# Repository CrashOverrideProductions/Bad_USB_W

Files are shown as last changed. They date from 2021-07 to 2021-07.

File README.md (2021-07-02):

# BadUSB-W 

### Project: Arduino and ESP32 Based WiFi Capable Malicious USB 

<!-- Repo Cover Image -->
<p style="background-color:rgba(22,22,22,1.00)" align="center">
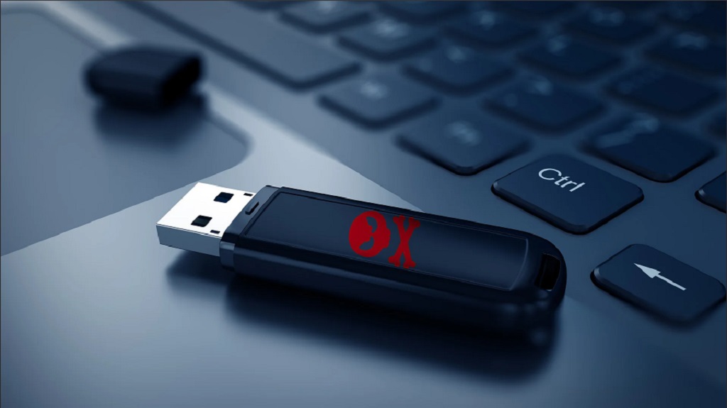
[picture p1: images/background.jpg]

</p>

<!-- Repo Stats -->
   

## Details
The BadUSB is intended to be a budget alternative to the current offering of Keystroke Injection tools available on the market.

### What is a Keystroke Injection Attack?
A Keystroke Injection Attack Tool is a specially designed USB device, often disguised as a thumb drive, that automatically runs code on any host computer into which it is plugged. It does so by appearing to the computer as a USB HID ('Human Interface Device') keyboard and/or mouse, and then “typing” in keyboard shortcuts and commands.

This can be a vector for malicious code, and is potentially dangerous and destructive! This project aims to educate you and your “victim” on the dangers of these devices. Nothing is quite so memorable a lesson in security as plugging in an innocent looking device and being met with a flurry of terminal windows and text popping up, and receiving an automatically deployed desktop background that says “You just go PWND, be more careful next time!"

---
<!-- To Do List -->
## To Do List
- [X] Complete Readme.md
- [X] Build & Test Prototype
- [ ] Design Schematic
- [ ] Finalise Software
- [ ] Design Board
- [ ] Order Prototype PCBs
- [ ] Design 3D Print Shell
- [ ] Research Injection Moulded Shell

---
## Prototype Design

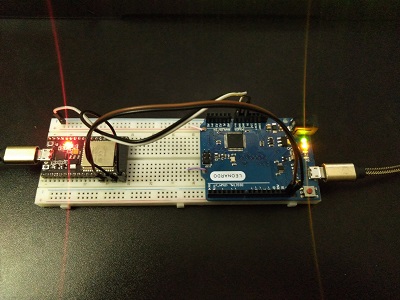
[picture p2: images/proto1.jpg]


### BOM
```
| COMPONENT         | QTY | AUD$   |
|===================|=====|========|
| ESP32 DEVKIT V1   |  1  | $39.95 |
| ARDUINO LEONARDO  |  1  | $29.95 |
```

### Software
The software for this project is a modified version of the WiFi Duck firmware developed by [SpaceHunn](https://github.com/SpacehuhnTech/WiFiDuck "SpaceHunn") released under the MIT Licence.

### Hardware Configuration
```
| LEONARDO          | ESP32 DEVKIT V1 | SIGNAL NAME |
|===================|=================|=============|
| SCL               | GPIO-22         | I2C SCL     |
| SDA               | GPIO-21         | I2C SDA     |
| GND               | GND             | GND         |
```

<!-- Licencing Always at the Bottom -->
------------
### Licencing 

**Creative Commons: Attribution - NonCommercial - ShareAlike 4.0 International (CC BY-NC-SA 4.0)**

**You are free to:**

**Share** — copy and redistribute the material in any medium or format

**Adapt** — remix, transform, and build upon the material

**Under the following terms:**

**Attribution** — You must give appropriate credit, provide a link to the license, and indicate if changes were made. You may do so in any reasonable manner, but not in any way that suggests the licensor endorses you or your use.

**NonCommercial** — You may not use the material for commercial purposes.

**ShareAlike** — If you remix, transform, or build upon the material, you must distribute your contributions under the same license as the original.

No additional restrictions — You may not apply legal terms or technological measures that legally restrict others from doing anything the license permits.

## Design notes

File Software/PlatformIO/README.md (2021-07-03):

# BadUSB-W Firmware 

### Project: PlatformIO Migration of BadUSB-W Firmware (WiFi Duck Modified) 



#### NOTE: THIS FIRMWARE IS CURRENTLY BEING MODIFIED FOR USE ON AN ESP32

#### ChangeLog
```c++
// PlatformIO Migration
22/05/2021  IMPORT SpacehuhnTech/WiFiDuck
22/05/2021  MIGRATE ESP_DUCK TO PLATFORMIO
22/05/2021  MIGRATE ATMEGA_DUCK TO PLATFORMIO

// ESP32 Migration
Date          File            Changes
==========    ============    ===================================================================
01/07/2021    cli.cpp         Comment out xtern "C" functions
01/07/2021    config.h        Enable Debugging
                              Enable I2C & Set Pin SDA-21/SCL-22
                              Change WiFi Settings (See WiFi Setting Below)
                              Change Sanity Check to from ESP8266 to ESP32
01/07/2021                    Manually Add Libraries "EEPROM" & "SPIFFS"
01/07/2021    eeprom.h        Change #include "<EEPROM.h>" to "#include "Libraries/EEPROM.h" "
01/07/2021    spiffs.cpp      Append "FILE_NAME" var with ".txt"
                              Change "size()" function to suit (See Addendum)
                              Change "usedBytes()" function to suit (See Addendum)
                              Change "freeBytes()" function to suit (See Addendum)
                              Change "size(String fileName)" function to suit (See Addendum)
                              Change "open(String fileName)" function to suit (See Addendum)
                              Change "create(String fileName)" function to suit (See Addendum)
                              Change "listDir(String dirName)" function to suit (See Addendum)
01/07/2021    spiffs.h        Add "#include "Libraries/SPIFFS.h"" 
                              Change "#include <FS.h>" to #include "Libraries/FS.h"
01/07/2021    webserver.cpp   Change "#include <ESP8266WiFi.h>" to "#include <WiFi.h>"
                              Change "#include <ESP8266mDNS.h>" to "#include <ESPmDNS.h>"
                              Change "#include <ESPAsyncTCP.h>" to "#include <AsyncTCP.h>"
                              omment out "Update.runAsync(true);"
```

ChangeLog Addendum
``` C++
spiffs.cpp
=============================================================================================
Change "size()" function to suit
    -------------------------------------------------------------------------
      // OLD FUNCTION
          size_t size() {
              FSInfo fs_info;

              SPIFFS.info(fs_info);
              return fs_info.totalBytes;
          }

      // NEW FUNCTION
          size_t size() {
              unsigned int totalBytes = SPIFFS.totalBytes();
              return totalBytes;
          }
    -------------------------------------------------------------------------

Change "usedBytes()" function to suit
    -------------------------------------------------------------------------
      // OLD FUNCTION
          size_t usedBytes() {
              FSInfo fs_info;

              SPIFFS.info(fs_info);
              return fs_info.usedBytes;
          }

      // NEW FUNCTION
          size_t usedBytes() {
            unsigned int usedBytes = SPIFFS.usedBytes();
            return usedBytes;
          }
    -------------------------------------------------------------------------

Change "freeBytes()" function to suit (See Addendum)
    -------------------------------------------------------------------------
      // OLD FUNCTION
          size_t freeBytes() {
                  FSInfo fs_info;

                  SPIFFS.info(fs_info);
                  return fs_info.totalBytes - fs_info.usedBytes;
              }

      // NEW FUNCTION
          size_t freeBytes() {
                  unsigned int totalBytes = SPIFFS.totalBytes();
                  unsigned int usedBytes = SPIFFS.usedBytes();

                  return (totalBytes - usedBytes);
              }
    -------------------------------------------------------------------------

Change "size(String fileName)" function to suit (See Addendum)
    -------------------------------------------------------------------------
      // OLD FUNCTION
            size_t size(String fileName) {
                fixPath(fileName);

                File f = SPIFFS.open(fileName, "r");

                return f.size();
            }

      // NEW FUNCTION
            size_t size(String fileName) {
                fixPath(fileName);

                File f = SPIFFS.open(fileName, FILE_READ);

                return f.size();
            }
    -------------------------------------------------------------------------

Change "open(String fileName)" function to suit (See Addendum)
    -------------------------------------------------------------------------
      // OLD FUNCTION
            File open(String fileName) {
                    fixPath(fileName);

                    return SPIFFS.open(fileName, "a+");
                }

      // NEW FUNCTION
            File open(String fileName) {
                fixPath(fileName);

                File file = SPIFFS.open(fileName, "r+");

                return file;
            }
    -------------------------------------------------------------------------

Change "create(String fileName)" function to suit (See Addendum)
    -------------------------------------------------------------------------
      // OLD FUNCTION
            void create(String fileName) {
              fixPath(fileName);

              File f = SPIFFS.open(fileName, "a+");

              f.close();
            }

      // NEW FUNCTION
            void create(String fileName) {
                    fixPath(fileName);

                    File f = SPIFFS.open(fileName, FILE_APPEND);

                    f.close();
            }
    -------------------------------------------------------------------------

Change "listDir(String dirName)" function to suit (See Addendum)
    -------------------------------------------------------------------------
      // OLD FUNCTION
            String listDir(String dirName) {
              String res;

              fixPath(dirName);

              Dir dir = SPIFFS.openDir(dirName);

              while (dir.next()) {
                  res += dir.fileName();
                  res += ' ';
                  res += size(dir.fileName());
                  res += '\n';
              }

              if (res.length() == 0) {
                  res += "\n";
              }

              return res;
            }
      // NEW FUNCTION
            String listDir(String dirName) {
                String res;

                fixPath(dirName);

                File root = SPIFFS.open(dirName);
              
                if(!root)
                {
                  debugln("failed to open directory");
                  return("Error!");
              }

                File file = root.openNextFile();
                while(file)
                {
                    //debugln(file.name());
                    res += file.name();
                    res += ' ';
                    res += size(file.name());
                    res += '\n';
                          
                    file = root.openNextFile();
                }

                if (res.length() == 0) 
                {
                    res += "\n";
                }
                    return res;
            }
    -------------------------------------------------------------------------

```

#### WiFi Settings
```python
WIFI_SSID       "BadUSBw"
WIFI_PASSWORD   "BadUSBW"
WIFI_CHANNEL    "1"
HOSTNAME        "badusb"
URL             "bad.usb"
```

#### Platform IO Build Status
##### ATMEGA_DUCK
```c++
Processing leonardo (platform: atmelavr; board: leonardo; framework: arduino)
------------------------------------------------------------------------------------------
Verbose mode can be enabled via `-v, --verbose` option
CONFIGURATION: https://docs.platformio.org/page/boards/atmelavr/leonardo.html
PLATFORM: Atmel AVR (3.3.0) > Arduino Leonardo    
HARDWARE: ATMEGA32U4 16MHz, 2.50KB RAM, 28KB Flash
DEBUG: Current (simavr) On-board (simavr)
PACKAGES:
 - framework-arduino-avr 5.1.0
 - toolchain-atmelavr 1.70300.191015 (7.3.0)      
LDF: Library Dependency Finder -> http://bit.ly/configure-pio-ldf
LDF Modes: Finder ~ chain, Compatibility ~ soft
Found 5 compatible libraries
Scanning dependencies...
Dependency Graph
|-- <SPI> 1.0 
|-- <Wire> 1.0
|-- <HID> 1.0 
Building in release mode
Compiling .pio\build\leonardo\src\Adafruit_DotStar.cpp.o
Compiling .pio\build\leonardo\src\NeoPixel.cpp.o
Compiling .pio\build\leonardo\src\atmega_duck.cpp.o
Compiling .pio\build\leonardo\src\com.cpp.o
Compiling .pio\build\leonardo\src\duckparser.cpp.o
Compiling .pio\build\leonardo\src\keyboard.cpp.o
Compiling .pio\build\leonardo\src\led.cpp.o
Compiling .pio\build\leonardo\src\parser.c.o
Compiling .pio\build\leonardo\FrameworkArduino\HardwareSerial.cpp.o
Compiling .pio\build\leonardo\FrameworkArduino\HardwareSerial0.cpp.o
Compiling .pio\build\leonardo\FrameworkArduino\HardwareSerial1.cpp.o
Archiving .pio\build\leonardo\lib675\libSPI.a
Compiling .pio\build\leonardo\FrameworkArduino\HardwareSerial2.cpp.o
Archiving .pio\build\leonardo\libdea\libWire.a
Archiving .pio\build\leonardo\lib370\libHID.a
Compiling .pio\build\leonardo\FrameworkArduino\HardwareSerial3.cpp.o
Compiling .pio\build\leonardo\FrameworkArduino\IPAddress.cpp.o
Compiling .pio\build\leonardo\FrameworkArduino\PluggableUSB.cpp.o
Compiling .pio\build\leonardo\FrameworkArduino\Print.cpp.o
Compiling .pio\build\leonardo\FrameworkArduino\Stream.cpp.o
Compiling .pio\build\leonardo\FrameworkArduino\Tone.cpp.o
Compiling .pio\build\leonardo\FrameworkArduino\USBCore.cpp.o
Compiling .pio\build\leonardo\FrameworkArduino\WInterrupts.c.o
Compiling .pio\build\leonardo\FrameworkArduino\WMath.cpp.o
Compiling .pio\build\leonardo\FrameworkArduino\WString.cpp.o
Compiling .pio\build\leonardo\FrameworkArduino\abi.cpp.o
Compiling .pio\build\leonardo\FrameworkArduino\hooks.c.o
Compiling .pio\build\leonardo\FrameworkArduino\main.cpp.o
Compiling .pio\build\leonardo\FrameworkArduino\new.cpp.o
Compiling .pio\build\leonardo\FrameworkArduino\wiring.c.o
Compiling .pio\build\leonardo\FrameworkArduino\wiring_analog.c.o
Compiling .pio\build\leonardo\FrameworkArduino\wiring_digital.c.o
Compiling .pio\build\leonardo\FrameworkArduino\wiring_pulse.S.o
Compiling .pio\build\leonardo\FrameworkArduino\wiring_pulse.c.o
Compiling .pio\build\leonardo\FrameworkArduino\wiring_shift.c.o
Archiving .pio\build\leonardo\libFrameworkArduino.a
Linking .pio\build\leonardo\firmware.elf
Checking size .pio\build\leonardo\firmware.elf
Advanced Memory Usage is available via "PlatformIO Home > Project Inspect"
RAM:   [======    ]  63.7% (used 1630 bytes from 2560 bytes)
Flash: [=====     ]  50.6% (used 14500 bytes from 28672 bytes)
Building .pio\build\leonardo\firmware.hex
=========================== [SUCCESS] Took 7.83 seconds ==================================
```

##### ESP_DUCK
```c++

Processing esp32doit-devkit-v1 (platform: espressif32; board: esp32doit-devkit-v1; framework: arduino)
------------------------------------------------------------------------------------------------------
Verbose mode can be enabled via `-v, --verbose` option
CONFIGURATION: https://docs.platformio.org/page/boards/espressif32/esp32doit-devkit-v1.html
PLATFORM: Espressif 32 (3.2.1) > DOIT ESP32 DEVKIT V1
HARDWARE: ESP32 240MHz, 320KB RAM, 4MB Flash
DEBUG: Current (esp-prog) External (esp-prog, iot-bus-jtag, jlink, minimodule, olimex-arm-usb-ocd,
 olimex-arm-usb-ocd-h, olimex-arm-usb-tiny-h, olimex-jtag-tiny, tumpa)
PACKAGES:
 - framework-arduinoespressif32 3.10006.210326 (1.0.6)
 - tool-esptoolpy 1.30000.201119 (3.0.0)
 - toolchain-xtensa32 2.50200.97 (5.2.0)
LDF: Library Dependency Finder -> http://bit.ly/configure-pio-ldf
LDF Modes: Finder ~ chain, Compatibility ~ soft
Found 31 compatible libraries
Scanning dependencies...
Dependency Graph
|-- <SimpleCLI> 1.1.1
|-- <ESP Async WebServer> 1.2.3
|   |-- <AsyncTCP> 1.1.1       
|   |-- <FS> 1.0
|   |-- <WiFi> 1.0
|-- <Wire> 1.0.1
|-- <ArduinoOTA> 1.0
|   |-- <Update> 1.0
|   |-- <WiFi> 1.0
|   |-- <ESPmDNS> 1.0
|   |   |-- <WiFi> 1.0
|-- <AsyncTCP> 1.1.1
|-- <DNSServer> 1.1.0
|   |-- <WiFi> 1.0
|-- <ESPmDNS> 1.0
|   |-- <WiFi> 1.0
|-- <WiFi> 1.0
Building in release mode
Compiling .pio\build\esp32doit-devkit-v1\src\Libraries\EEPROM.cpp.o
Compiling .pio\build\esp32doit-devkit-v1\src\Libraries\FS.cpp.o
Compiling .pio\build\esp32doit-devkit-v1\src\Libraries\SPIFFS.cpp.o
Compiling .pio\build\esp32doit-devkit-v1\src\Libraries\vfs_api.cpp.o
Compiling .pio\build\esp32doit-devkit-v1\src\cli.cpp.o
Compiling .pio\build\esp32doit-devkit-v1\src\com.cpp.o
Compiling .pio\build\esp32doit-devkit-v1\src\duckscript.cpp.o
Compiling .pio\build\esp32doit-devkit-v1\src\eeprom.cpp.o
Compiling .pio\build\esp32doit-devkit-v1\src\esp_duck.cpp.o
Compiling .pio\build\esp32doit-devkit-v1\src\settings.cpp.o
Compiling .pio\build\esp32doit-devkit-v1\src\spiffs.cpp.o
Compiling .pio\build\esp32doit-devkit-v1\src\webserver.cpp.o
Generating partitions .pio\build\esp32doit-devkit-v1\partitions.bin
Compiling .pio\build\esp32doit-devkit-v1\lib176\SimpleCLI\Argument.cpp.o
Compiling .pio\build\esp32doit-devkit-v1\lib176\SimpleCLI\Command.cpp.o
Compiling .pio\build\esp32doit-devkit-v1\lib176\SimpleCLI\CommandError.cpp.o
Compiling .pio\build\esp32doit-devkit-v1\lib176\SimpleCLI\SimpleCLI.cpp.o
Compiling .pio\build\esp32doit-devkit-v1\lib176\SimpleCLI\c\arg.c.o
Compiling .pio\build\esp32doit-devkit-v1\lib176\SimpleCLI\c\cmd.c.o
Compiling .pio\build\esp32doit-devkit-v1\lib176\SimpleCLI\c\cmd_error.c.o
Compiling .pio\build\esp32doit-devkit-v1\lib176\SimpleCLI\c\comparator.c.o
Compiling .pio\build\esp32doit-devkit-v1\lib176\SimpleCLI\c\parser.c.o
Compiling .pio\build\esp32doit-devkit-v1\libb5f\AsyncTCP\AsyncTCP.cpp.o
Compiling .pio\build\esp32doit-devkit-v1\libb9a\FS\FS.cpp.o
Compiling .pio\build\esp32doit-devkit-v1\libb9a\FS\vfs_api.cpp.o
Compiling .pio\build\esp32doit-devkit-v1\libb1c\WiFi\ETH.cpp.o
Compiling .pio\build\esp32doit-devkit-v1\libb1c\WiFi\WiFi.cpp.o
Compiling .pio\build\esp32doit-devkit-v1\libb1c\WiFi\WiFiAP.cpp.o
Archiving .pio\build\esp32doit-devkit-v1\lib176\libSimpleCLI.a
Compiling .pio\build\esp32doit-devkit-v1\libb1c\WiFi\WiFiClient.cpp.o
Compiling .pio\build\esp32doit-devkit-v1\libb1c\WiFi\WiFiGeneric.cpp.o
Compiling .pio\build\esp32doit-devkit-v1\libb1c\WiFi\WiFiMulti.cpp.o
Archiving .pio\build\esp32doit-devkit-v1\libb9a\libFS.a
Compiling .pio\build\esp32doit-devkit-v1\libb1c\WiFi\WiFiSTA.cpp.o
Compiling .pio\build\esp32doit-devkit-v1\libb1c\WiFi\WiFiScan.cpp.o
Archiving .pio\build\esp32doit-devkit-v1\libb5f\libAsyncTCP.a
Compiling .pio\build\esp32doit-devkit-v1\libb1c\WiFi\WiFiServer.cpp.o
Compiling .pio\build\esp32doit-devkit-v1\libb1c\WiFi\WiFiUdp.cpp.o
Compiling .pio\build\esp32doit-devkit-v1\lib632\ESP Async WebServer\AsyncEventSource.cpp.o
Compiling .pio\build\esp32doit-devkit-v1\lib632\ESP Async WebServer\AsyncWebSocket.cpp.o
Compiling .pio\build\esp32doit-devkit-v1\lib632\ESP Async WebServer\SPIFFSEditor.cpp.o
Compiling .pio\build\esp32doit-devkit-v1\lib632\ESP Async WebServer\WebAuthentication.cpp.o
Compiling .pio\build\esp32doit-devkit-v1\lib632\ESP Async WebServer\WebHandlers.cpp.o
Compiling .pio\build\esp32doit-devkit-v1\lib632\ESP Async WebServer\WebRequest.cpp.o
Compiling .pio\build\esp32doit-devkit-v1\lib632\ESP Async WebServer\WebResponses.cpp.o
Archiving .pio\build\esp32doit-devkit-v1\libb1c\libWiFi.a
Compiling .pio\build\esp32doit-devkit-v1\lib632\ESP Async WebServer\WebServer.cpp.o
Compiling .pio\build\esp32doit-devkit-v1\lib068\Wire\Wire.cpp.o
Compiling .pio\build\esp32doit-devkit-v1\lib178\Update\HttpsOTAUpdate.cpp.o
Compiling .pio\build\esp32doit-devkit-v1\lib178\Update\Updater.cpp.o
Compiling .pio\build\esp32doit-devkit-v1\libcf5\ESPmDNS\ESPmDNS.cpp.o
Compiling .pio\build\esp32doit-devkit-v1\liba79\ArduinoOTA\ArduinoOTA.cpp.o
Compiling .pio\build\esp32doit-devkit-v1\libd96\DNSServer\DNSServer.cpp.o
Archiving .pio\build\esp32doit-devkit-v1\libFrameworkArduinoVariant.a
Compiling .pio\build\esp32doit-devkit-v1\FrameworkArduino\Esp.cpp.o
Archiving .pio\build\esp32doit-devkit-v1\lib068\libWire.a
Compiling .pio\build\esp32doit-devkit-v1\FrameworkArduino\FunctionalInterrupt.cpp.o
Compiling .pio\build\esp32doit-devkit-v1\FrameworkArduino\HardwareSerial.cpp.o
Archiving .pio\build\esp32doit-devkit-v1\lib178\libUpdate.a
Compiling .pio\build\esp32doit-devkit-v1\FrameworkArduino\IPAddress.cpp.o
Compiling .pio\build\esp32doit-devkit-v1\FrameworkArduino\IPv6Address.cpp.o
Archiving .pio\build\esp32doit-devkit-v1\libcf5\libESPmDNS.a
Compiling .pio\build\esp32doit-devkit-v1\FrameworkArduino\MD5Builder.cpp.o
Archiving .pio\build\esp32doit-devkit-v1\liba79\libArduinoOTA.a
Archiving .pio\build\esp32doit-devkit-v1\libd96\libDNSServer.a
Compiling .pio\build\esp32doit-devkit-v1\FrameworkArduino\Print.cpp.o
Compiling .pio\build\esp32doit-devkit-v1\FrameworkArduino\Stream.cpp.o
Compiling .pio\build\esp32doit-devkit-v1\FrameworkArduino\StreamString.cpp.o
Compiling .pio\build\esp32doit-devkit-v1\FrameworkArduino\WMath.cpp.o
Archiving .pio\build\esp32doit-devkit-v1\lib632\libESP Async WebServer.a
Compiling .pio\build\esp32doit-devkit-v1\FrameworkArduino\WString.cpp.o
Compiling .pio\build\esp32doit-devkit-v1\FrameworkArduino\base64.cpp.o
Compiling .pio\build\esp32doit-devkit-v1\FrameworkArduino\cbuf.cpp.o
Compiling .pio\build\esp32doit-devkit-v1\FrameworkArduino\esp32-hal-adc.c.o
Compiling .pio\build\esp32doit-devkit-v1\FrameworkArduino\esp32-hal-bt.c.o
Compiling .pio\build\esp32doit-devkit-v1\FrameworkArduino\esp32-hal-cpu.c.o
Compiling .pio\build\esp32doit-devkit-v1\FrameworkArduino\esp32-hal-dac.c.o
Compiling .pio\build\esp32doit-devkit-v1\FrameworkArduino\esp32-hal-gpio.c.o
Compiling .pio\build\esp32doit-devkit-v1\FrameworkArduino\esp32-hal-i2c.c.o
Compiling .pio\build\esp32doit-devkit-v1\FrameworkArduino\esp32-hal-ledc.c.o
Compiling .pio\build\esp32doit-devkit-v1\FrameworkArduino\esp32-hal-log.c.o
Compiling .pio\build\esp32doit-devkit-v1\FrameworkArduino\esp32-hal-matrix.c.o
Compiling .pio\build\esp32doit-devkit-v1\FrameworkArduino\esp32-hal-misc.c.o
Compiling .pio\build\esp32doit-devkit-v1\FrameworkArduino\esp32-hal-psram.c.o
Compiling .pio\build\esp32doit-devkit-v1\FrameworkArduino\esp32-hal-rmt.c.o
Compiling .pio\build\esp32doit-devkit-v1\FrameworkArduino\esp32-hal-sigmadelta.c.o
Compiling .pio\build\esp32doit-devkit-v1\FrameworkArduino\esp32-hal-spi.c.o
Compiling .pio\build\esp32doit-devkit-v1\FrameworkArduino\esp32-hal-time.c.o
Compiling .pio\build\esp32doit-devkit-v1\FrameworkArduino\esp32-hal-timer.c.o
Compiling .pio\build\esp32doit-devkit-v1\FrameworkArduino\esp32-hal-touch.c.o
Compiling .pio\build\esp32doit-devkit-v1\FrameworkArduino\esp32-hal-uart.c.o
Compiling .pio\build\esp32doit-devkit-v1\FrameworkArduino\libb64\cdecode.c.o
Compiling .pio\build\esp32doit-devkit-v1\FrameworkArduino\libb64\cencode.c.o
Compiling .pio\build\esp32doit-devkit-v1\FrameworkArduino\main.cpp.o
Compiling .pio\build\esp32doit-devkit-v1\FrameworkArduino\stdlib_noniso.c.o
Compiling .pio\build\esp32doit-devkit-v1\FrameworkArduino\wiring_pulse.c.o
Compiling .pio\build\esp32doit-devkit-v1\FrameworkArduino\wiring_shift.c.o
Archiving .pio\build\esp32doit-devkit-v1\libFrameworkArduino.a
Linking .pio\build\esp32doit-devkit-v1\firmware.elf
Retrieving maximum program size .pio\build\esp32doit-devkit-v1\firmware.elf
Checking size .pio\build\esp32doit-devkit-v1\firmware.elf
Advanced Memory Usage is available via "PlatformIO Home > Project Inspect"
RAM:   [=         ]  14.9% (used 48828 bytes from 327680 bytes)
Flash: [========= ]  85.3% (used 1117514 bytes from 1310720 bytes)
Building .pio\build\esp32doit-devkit-v1\firmware.bin
esptool.py v3.0
================================================================================================================
                                        [SUCCESS] Took 48.71 seconds 
================================================================================================================
```

<!-- Licencing Always at the Bottom -->
------------
### Licencing 

**MIT - LICENCE**
Permission is hereby granted, free of charge, to any person obtaining a copy of this software and associated documentation files (the "Software"), to deal in the Software without restriction, including without limitation the rights to use, copy, modify, merge, publish, distribute, sublicense, and/or sell copies of the Software, and to permit persons to whom the Software is furnished to do so, subject to the following conditions: 
* The above copyright notice and this permission notice shall be included in all copies or substantial portions of the Software. 

* THE SOFTWARE IS PROVIDED "AS IS", WITHOUT WARRANTY OF ANY KIND, EXPRESS OR IMPLIED, INCLUDING BUT NOT LIMITED TO THE WARRANTIES OF MERCHANTABILITY, FITNESS FOR A PARTICULAR PURPOSE AND NONINFRINGEMENT. 

* IN NO EVENT SHALL THE AUTHORS OR COPYRIGHT HOLDERS BE LIABLE FOR ANY CLAIM, DAMAGES OR OTHER LIABILITY, WHETHER IN AN ACTION OF CONTRACT, TORT OR OTHERWISE, ARISING FROM, OUT OF OR IN CONNECTION WITH THE SOFTWARE OR THE USE OR OTHER DEALINGS IN THE SOFTWARE.

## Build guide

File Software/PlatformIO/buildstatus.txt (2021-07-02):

Processing esp32doit-devkit-v1 (platform: espressif32; board: esp32doit-devkit-v1; framework: arduino)
-------------------------------------------------------------------------------------------------------------------------------------------------------------------------------------------------------------------------------------------------------------------------Verbose mode can be enabled via `-v, --verbose` option
CONFIGURATION: https://docs.platformio.org/page/boards/espressif32/esp32doit-devkit-v1.html
PLATFORM: Espressif 32 (3.2.1) > DOIT ESP32 DEVKIT V1
HARDWARE: ESP32 240MHz, 320KB RAM, 4MB Flash
DEBUG: Current (esp-prog) External (esp-prog, iot-bus-jtag, jlink, minimodule, olimex-arm-usb-ocd, olimex-arm-usb-ocd-h, olimex-arm-usb-tiny-h, olimex-jtag-tiny, tumpa)
PACKAGES:
 - framework-arduinoespressif32 3.10006.210326 (1.0.6)
 - tool-esptoolpy 1.30000.201119 (3.0.0)
 - toolchain-xtensa32 2.50200.97 (5.2.0)
LDF: Library Dependency Finder -> http://bit.ly/configure-pio-ldf
LDF Modes: Finder ~ chain, Compatibility ~ soft
Found 31 compatible libraries
Scanning dependencies...
Dependency Graph
|-- <SimpleCLI> 1.1.1
|-- <ESP Async WebServer> 1.2.3
|   |-- <AsyncTCP> 1.1.1       
|   |-- <FS> 1.0
|   |-- <WiFi> 1.0
|-- <Wire> 1.0.1
|-- <ArduinoOTA> 1.0
|   |-- <Update> 1.0
|   |-- <WiFi> 1.0
|   |-- <ESPmDNS> 1.0
|   |   |-- <WiFi> 1.0
|-- <AsyncTCP> 1.1.1
|-- <DNSServer> 1.1.0
|   |-- <WiFi> 1.0
|-- <ESPmDNS> 1.0
|   |-- <WiFi> 1.0
|-- <WiFi> 1.0
Building in release mode
Compiling .pio\build\esp32doit-devkit-v1\src\Libraries\EEPROM.cpp.o
Compiling .pio\build\esp32doit-devkit-v1\src\Libraries\FS.cpp.o
Compiling .pio\build\esp32doit-devkit-v1\src\Libraries\SPIFFS.cpp.o
Compiling .pio\build\esp32doit-devkit-v1\src\Libraries\vfs_api.cpp.o
Compiling .pio\build\esp32doit-devkit-v1\src\cli.cpp.o
Compiling .pio\build\esp32doit-devkit-v1\src\com.cpp.o
Compiling .pio\build\esp32doit-devkit-v1\src\duckscript.cpp.o
Compiling .pio\build\esp32doit-devkit-v1\src\eeprom.cpp.o
src\com.cpp: In function 'void com::i2c_begin()':
src\com.cpp:113:23: warning: unused variable 'start_time' [-Wunused-variable]
         unsigned long start_time = millis();
                       ^
src\cli.cpp: In lambda function:
src\cli.cpp:84:30: warning: 'uint32_t system_get_free_heap_size()' is deprecated [-Wdeprecated-declarations]
             size_t freeRam = system_get_free_heap_size();
                              ^
In file included from C:\Users\Justin\.platformio\packages\framework-arduinoespressif32\tools\sdk\include\freertos/freertos/portable.h:128:0,
                 from C:\Users\Justin\.platformio\packages\framework-arduinoespressif32\tools\sdk\include\freertos/freertos/FreeRTOS.h:105,
                 from C:\Users\Justin\.platformio\packages\framework-arduinoespressif32\cores\esp32/Arduino.h:32,
                 from src\cli.h:10,
                 from src\cli.cpp:8:
C:\Users\Justin\.platformio\packages\framework-arduinoespressif32\tools\sdk\include\esp32/esp_system.h:152:10: note: declared here
 uint32_t system_get_free_heap_size(void)  __attribute__ ((deprecated));
          ^
src\cli.cpp:84:30: warning: 'uint32_t system_get_free_heap_size()' is deprecated [-Wdeprecated-declarations]
             size_t freeRam = system_get_free_heap_size();
                              ^
In file included from C:\Users\Justin\.platformio\packages\framework-arduinoespressif32\tools\sdk\include\freertos/freertos/portable.h:128:0,
                 from C:\Users\Justin\.platformio\packages\framework-arduinoespressif32\tools\sdk\include\freertos/freertos/FreeRTOS.h:105,
                 from C:\Users\Justin\.platformio\packages\framework-arduinoespressif32\cores\esp32/Arduino.h:32,
                 from src\cli.h:10,
                 from src\cli.cpp:8:
C:\Users\Justin\.platformio\packages\framework-arduinoespressif32\tools\sdk\include\esp32/esp_system.h:152:10: note: declared here
 uint32_t system_get_free_heap_size(void)  __attribute__ ((deprecated));
          ^
src\cli.cpp:84:56: warning: 'uint32_t system_get_free_heap_size()' is deprecated [-Wdeprecated-declarations]
             size_t freeRam = system_get_free_heap_size();
                                                        ^
In file included from C:\Users\Justin\.platformio\packages\framework-arduinoespressif32\tools\sdk\include\freertos/freertos/portable.h:128:0,
                 from C:\Users\Justin\.platformio\packages\framework-arduinoespressif32\tools\sdk\include\freertos/freertos/FreeRTOS.h:105,
                 from C:\Users\Justin\.platformio\packages\framework-arduinoespressif32\cores\esp32/Arduino.h:32,
                 from src\cli.h:10,
                 from src\cli.cpp:8:
C:\Users\Justin\.platformio\packages\framework-arduinoespressif32\tools\sdk\include\esp32/esp_system.h:152:10: note: declared here
 uint32_t system_get_free_heap_size(void)  __attribute__ ((deprecated));
          ^
src\cli.cpp: In lambda function:
src\cli.cpp:404:24: warning: unused variable 'read' [-Wunused-variable]
                 size_t read = spiffs::streamRead(buffer, len);
                        ^
Compiling .pio\build\esp32doit-devkit-v1\src\esp_duck.cpp.o
Compiling .pio\build\esp32doit-devkit-v1\src\settings.cpp.o
Compiling .pio\build\esp32doit-devkit-v1\src\spiffs.cpp.o
Compiling .pio\build\esp32doit-devkit-v1\src\webserver.cpp.o
Generating partitions .pio\build\esp32doit-devkit-v1\partitions.bin
Compiling .pio\build\esp32doit-devkit-v1\lib176\SimpleCLI\Argument.cpp.o
Compiling .pio\build\esp32doit-devkit-v1\lib176\SimpleCLI\Command.cpp.o
Compiling .pio\build\esp32doit-devkit-v1\lib176\SimpleCLI\CommandError.cpp.o
Compiling .pio\build\esp32doit-devkit-v1\lib176\SimpleCLI\SimpleCLI.cpp.o
src\settings.cpp: In function 'void settings::reset()':
src\settings.cpp:46:38: warning: statement has no effect [-Wunused-value]
         debugln("Resetting Settings");
                                      ^
src\settings.cpp: In function 'void settings::save()':
src\settings.cpp:54:35: warning: statement has no effect [-Wunused-value]
         debugln("Saving Settings");
                                   ^
Compiling .pio\build\esp32doit-devkit-v1\lib176\SimpleCLI\c\arg.c.o
Compiling .pio\build\esp32doit-devkit-v1\lib176\SimpleCLI\c\cmd.c.o
Compiling .pio\build\esp32doit-devkit-v1\lib176\SimpleCLI\c\cmd_error.c.o
Compiling .pio\build\esp32doit-devkit-v1\lib176\SimpleCLI\c\comparator.c.o
Compiling .pio\build\esp32doit-devkit-v1\lib176\SimpleCLI\c\parser.c.o
Compiling .pio\build\esp32doit-devkit-v1\libb5f\AsyncTCP\AsyncTCP.cpp.o
Compiling .pio\build\esp32doit-devkit-v1\libb9a\FS\FS.cpp.o
Compiling .pio\build\esp32doit-devkit-v1\libb9a\FS\vfs_api.cpp.o
Compiling .pio\build\esp32doit-devkit-v1\libb1c\WiFi\ETH.cpp.o
Compiling .pio\build\esp32doit-devkit-v1\libb1c\WiFi\WiFi.cpp.o
Compiling .pio\build\esp32doit-devkit-v1\libb1c\WiFi\WiFiAP.cpp.o
Archiving .pio\build\esp32doit-devkit-v1\lib176\libSimpleCLI.a
Compiling .pio\build\esp32doit-devkit-v1\libb1c\WiFi\WiFiClient.cpp.o
Compiling .pio\build\esp32doit-devkit-v1\libb1c\WiFi\WiFiGeneric.cpp.o
Compiling .pio\build\esp32doit-devkit-v1\libb1c\WiFi\WiFiMulti.cpp.o
Archiving .pio\build\esp32doit-devkit-v1\libb9a\libFS.a
Compiling .pio\build\esp32doit-devkit-v1\libb1c\WiFi\WiFiSTA.cpp.o
Compiling .pio\build\esp32doit-devkit-v1\libb1c\WiFi\WiFiScan.cpp.o
Archiving .pio\build\esp32doit-devkit-v1\libb5f\libAsyncTCP.a
Compiling .pio\build\esp32doit-devkit-v1\libb1c\WiFi\WiFiServer.cpp.o
Compiling .pio\build\esp32doit-devkit-v1\libb1c\WiFi\WiFiUdp.cpp.o
Compiling .pio\build\esp32doit-devkit-v1\lib632\ESP Async WebServer\AsyncEventSource.cpp.o
Compiling .pio\build\esp32doit-devkit-v1\lib632\ESP Async WebServer\AsyncWebSocket.cpp.o
Compiling .pio\build\esp32doit-devkit-v1\lib632\ESP Async WebServer\SPIFFSEditor.cpp.o
Compiling .pio\build\esp32doit-devkit-v1\lib632\ESP Async WebServer\WebAuthentication.cpp.o
Compiling .pio\build\esp32doit-devkit-v1\lib632\ESP Async WebServer\WebHandlers.cpp.o
Compiling .pio\build\esp32doit-devkit-v1\lib632\ESP Async WebServer\WebRequest.cpp.o
Compiling .pio\build\esp32doit-devkit-v1\lib632\ESP Async WebServer\WebResponses.cpp.o
Archiving .pio\build\esp32doit-devkit-v1\libb1c\libWiFi.a
Compiling .pio\build\esp32doit-devkit-v1\lib632\ESP Async WebServer\WebServer.cpp.o
Compiling .pio\build\esp32doit-devkit-v1\lib068\Wire\Wire.cpp.o
Compiling .pio\build\esp32doit-devkit-v1\lib178\Update\HttpsOTAUpdate.cpp.o
Compiling .pio\build\esp32doit-devkit-v1\lib178\Update\Updater.cpp.o
Compiling .pio\build\esp32doit-devkit-v1\libcf5\ESPmDNS\ESPmDNS.cpp.o
Compiling .pio\build\esp32doit-devkit-v1\liba79\ArduinoOTA\ArduinoOTA.cpp.o
Compiling .pio\build\esp32doit-devkit-v1\libd96\DNSServer\DNSServer.cpp.o
Archiving .pio\build\esp32doit-devkit-v1\libFrameworkArduinoVariant.a
Compiling .pio\build\esp32doit-devkit-v1\FrameworkArduino\Esp.cpp.o
Archiving .pio\build\esp32doit-devkit-v1\lib068\libWire.a
Compiling .pio\build\esp32doit-devkit-v1\FrameworkArduino\FunctionalInterrupt.cpp.o
Compiling .pio\build\esp32doit-devkit-v1\FrameworkArduino\HardwareSerial.cpp.o
Archiving .pio\build\esp32doit-devkit-v1\lib178\libUpdate.a
Compiling .pio\build\esp32doit-devkit-v1\FrameworkArduino\IPAddress.cpp.o
Compiling .pio\build\esp32doit-devkit-v1\FrameworkArduino\IPv6Address.cpp.o
Archiving .pio\build\esp32doit-devkit-v1\libcf5\libESPmDNS.a
Compiling .pio\build\esp32doit-devkit-v1\FrameworkArduino\MD5Builder.cpp.o
Archiving .pio\build\esp32doit-devkit-v1\liba79\libArduinoOTA.a
Archiving .pio\build\esp32doit-devkit-v1\libd96\libDNSServer.a
Compiling .pio\build\esp32doit-devkit-v1\FrameworkArduino\Print.cpp.o
Compiling .pio\build\esp32doit-devkit-v1\FrameworkArduino\Stream.cpp.o
Compiling .pio\build\esp32doit-devkit-v1\FrameworkArduino\StreamString.cpp.o
Compiling .pio\build\esp32doit-devkit-v1\FrameworkArduino\WMath.cpp.o
Archiving .pio\build\esp32doit-devkit-v1\lib632\libESP Async WebServer.a
Compiling .pio\build\esp32doit-devkit-v1\FrameworkArduino\WString.cpp.o
Compiling .pio\build\esp32doit-devkit-v1\FrameworkArduino\base64.cpp.o
Compiling .pio\build\esp32doit-devkit-v1\FrameworkArduino\cbuf.cpp.o
Compiling .pio\build\esp32doit-devkit-v1\FrameworkArduino\esp32-hal-adc.c.o
Compiling .pio\build\esp32doit-devkit-v1\FrameworkArduino\esp32-hal-bt.c.o
Compiling .pio\build\esp32doit-devkit-v1\FrameworkArduino\esp32-hal-cpu.c.o
Compiling .pio\build\esp32doit-devkit-v1\FrameworkArduino\esp32-hal-dac.c.o
Compiling .pio\build\esp32doit-devkit-v1\FrameworkArduino\esp32-hal-gpio.c.o
Compiling .pio\build\esp32doit-devkit-v1\FrameworkArduino\esp32-hal-i2c.c.o
Compiling .pio\build\esp32doit-devkit-v1\FrameworkArduino\esp32-hal-ledc.c.o
Compiling .pio\build\esp32doit-devkit-v1\FrameworkArduino\esp32-hal-log.c.o
Compiling .pio\build\esp32doit-devkit-v1\FrameworkArduino\esp32-hal-matrix.c.o
Compiling .pio\build\esp32doit-devkit-v1\FrameworkArduino\esp32-hal-misc.c.o
Compiling .pio\build\esp32doit-devkit-v1\FrameworkArduino\esp32-hal-psram.c.o
Compiling .pio\build\esp32doit-devkit-v1\FrameworkArduino\esp32-hal-rmt.c.o
Compiling .pio\build\esp32doit-devkit-v1\FrameworkArduino\esp32-hal-sigmadelta.c.o
Compiling .pio\build\esp32doit-devkit-v1\FrameworkArduino\esp32-hal-spi.c.o
Compiling .pio\build\esp32doit-devkit-v1\FrameworkArduino\esp32-hal-time.c.o
Compiling .pio\build\esp32doit-devkit-v1\FrameworkArduino\esp32-hal-timer.c.o
Compiling .pio\build\esp32doit-devkit-v1\FrameworkArduino\esp32-hal-touch.c.o
Compiling .pio\build\esp32doit-devkit-v1\FrameworkArduino\esp32-hal-uart.c.o
C:\Users\Justin\.platformio\packages\framework-arduinoespressif32\cores\esp32\esp32-hal-spi.c: In function 'spiTransferBytesNL':
C:\Users\Justin\.platformio\packages\framework-arduinoespressif32\cores\esp32\esp32-hal-spi.c:922:39: warning: initialization from incompatible pointer type [-Wincompatible-pointer-types]
                 uint8_t * last_out8 = &result[c_longs-1];
                                       ^
C:\Users\Justin\.platformio\packages\framework-arduinoespressif32\cores\esp32\esp32-hal-spi.c:923:40: warning: initialization from incompatible pointer type [-Wincompatible-pointer-types]
                 uint8_t * last_data8 = &last_data;
                                        ^
Compiling .pio\build\esp32doit-devkit-v1\FrameworkArduino\libb64\cdecode.c.o
Compiling .pio\build\esp32doit-devkit-v1\FrameworkArduino\libb64\cencode.c.o
Compiling .pio\build\esp32doit-devkit-v1\FrameworkArduino\main.cpp.o
Compiling .pio\build\esp32doit-devkit-v1\FrameworkArduino\stdlib_noniso.c.o
Compiling .pio\build\esp32doit-devkit-v1\FrameworkArduino\wiring_pulse.c.o
Compiling .pio\build\esp32doit-devkit-v1\FrameworkArduino\wiring_shift.c.o
Archiving .pio\build\esp32doit-devkit-v1\libFrameworkArduino.a
Linking .pio\build\esp32doit-devkit-v1\firmware.elf
Retrieving maximum program size .pio\build\esp32doit-devkit-v1\firmware.elf
Checking size .pio\build\esp32doit-devkit-v1\firmware.elf
Advanced Memory Usage is available via "PlatformIO Home > Project Inspect"
RAM:   [=         ]  14.9% (used 48828 bytes from 327680 bytes)
Flash: [========= ]  85.3% (used 1117514 bytes from 1310720 bytes)
Building .pio\build\esp32doit-devkit-v1\firmware.bin
esptool.py v3.0
===================================================================================================================== [SUCCESS] Took 48.71 seconds =====================================================================================================================

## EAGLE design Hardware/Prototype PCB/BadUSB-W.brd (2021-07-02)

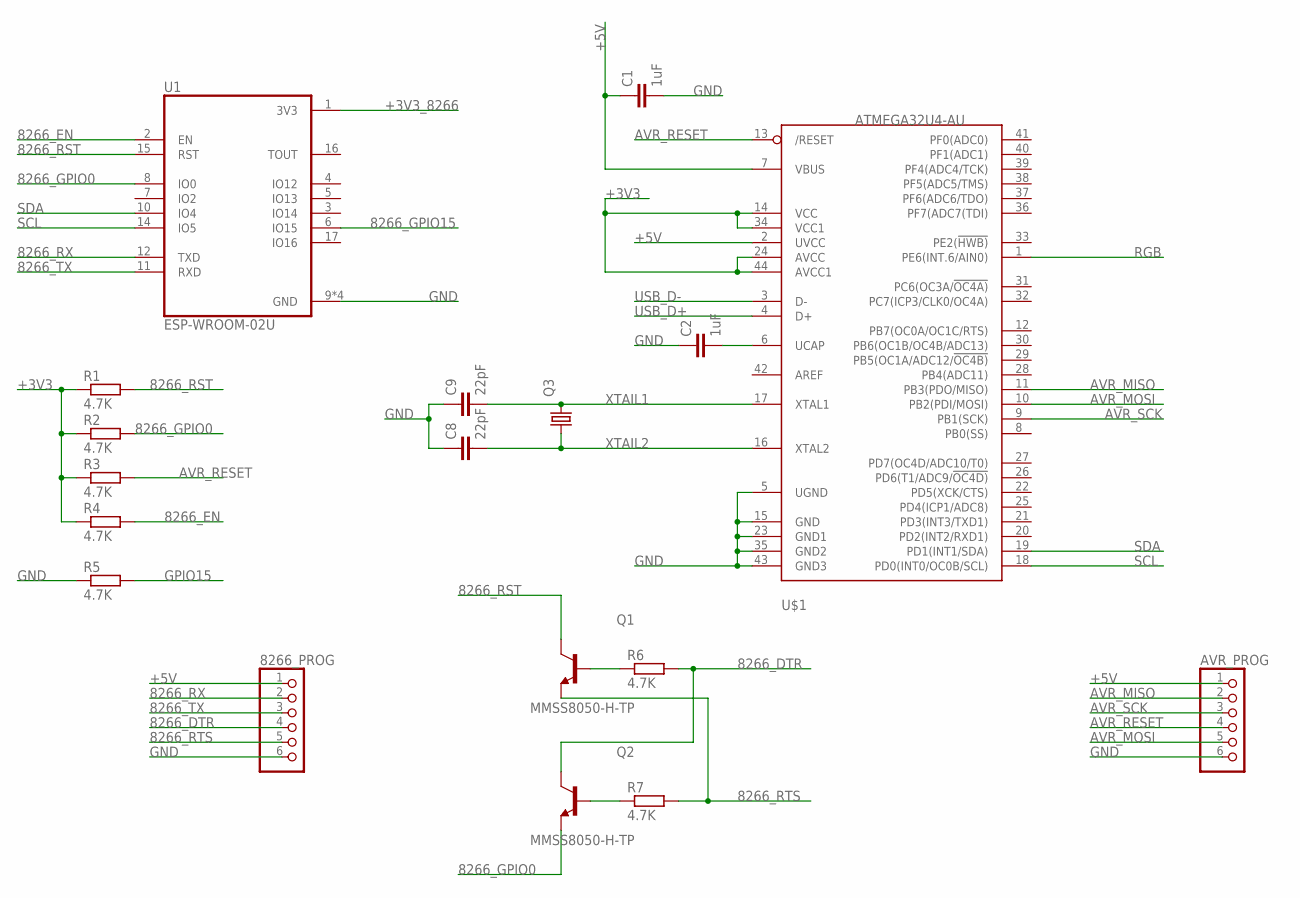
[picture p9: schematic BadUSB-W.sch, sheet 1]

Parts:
8266_PROG: PINHD-1X6; 1X06
AVR_PROG: PINHD-1X6; 1X06
C1, C2: 1uF; C0603K
C8, C9: 22pF; C0603K
Q1, Q2: MMSS8050-H-TP; TRANS_MMSS8050-H-TP
Q3: KX-7; 3.2X2.5_KX-7
R1, R2, R3, R4, R5, R6, R7: 4.7K; R0603
U1: ESP-WROOM-02U; MODULE_ESP-WROOM-02U
U$1: ATMEGA32U4-AU; TQFP44

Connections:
8266_DTR: 8266_PROG.4, Q2.3 (C), R6.2
8266_EN: R4.2, U1.2 (EN)
8266_GPIO0: Q2.2 (E), R2.2, U1.8 (IO0)
8266_GPIO15: U1.6 (IO15)
8266_RST: Q1.3 (C), R1.2, U1.15 (RST)
8266_RTS: 8266_PROG.5, Q1.2 (E), R7.2
8266_RX: 8266_PROG.2, U1.12 (TXD)
8266_TX: 8266_PROG.3, U1.11 (RXD)
+3V3: R1.1, R2.1, R3.1, R4.1, U$1.14 (VCC), U$1.24 (AVCC), U$1.34 (VCC1), U$1.44 (AVCC1); also elsewhere on the board
+3V3_8266: U1.1 (3V3)
+5V: 8266_PROG.1, AVR_PROG.1, C1.1, U$1.2 (UVCC), U$1.7 (VBUS); also elsewhere on the board
AVR_MISO: AVR_PROG.2, U$1.11 (PB3(PDO/MISO))
AVR_MOSI: AVR_PROG.5, U$1.10 (PB2(PDI/MOSI))
AVR_RESET: AVR_PROG.4, R3.2, U$1.13 (/RESET)
AVR_SCK: AVR_PROG.3, U$1.9 (PB1(SCK))
GND: 8266_PROG.6, AVR_PROG.6, C1.2, C2.1, C8.1, C9.1, R5.1, U1.9 (GND), U1.13 (GND), U1.18 (GND), U1.19 (GND), U$1.5 (UGND), U$1.15 (GND), U$1.23 (GND1), U$1.35 (GND2), U$1.43 (GND3); also elsewhere on the board
GPIO15: R5.2
unnamed: C2.2, U$1.6 (UCAP)
unnamed: Q1.1 (B), R6.1
unnamed: Q2.1 (B), R7.1
RGB: U$1.1 (PE6(INT.6/AIN0)); also elsewhere on the board
SCL: U1.14 (IO5), U$1.18 (PD0(INT0/OC0B/SCL))
SDA: U1.10 (IO4), U$1.19 (PD1(INT1/SDA))
USB_D+: U$1.4 (D+); also elsewhere on the board
USB_D-: U$1.3 (D-); also elsewhere on the board
XTAIL1: C9.2, Q3.3 (2), U$1.17 (XTAL1)
XTAIL2: C8.2, Q3.1, U$1.16 (XTAL2)

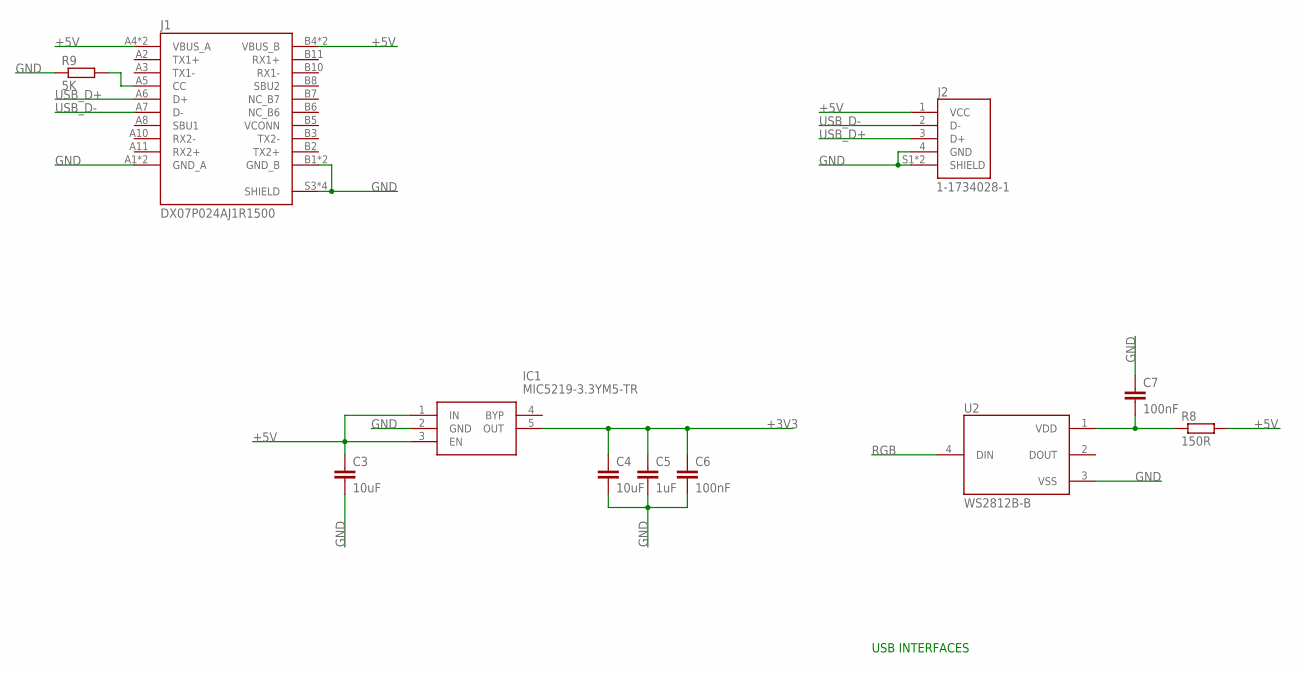
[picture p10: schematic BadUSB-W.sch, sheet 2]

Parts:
C3, C4: 10uF; C0603K
C5: 1uF; C0603K
C6, C7: 100nF; C0603K
IC1: MIC5219-3.3YM5-TR; SOT95P280X130-5N
J1: DX07P024AJ1R1500; JAE_DX07P024AJ1R1500
J2: 1-1734028-1; TE_1-1734028-1
R8: 150R; R0603
R9: 5K; R0603
U2: WS2812B-B; LED_WS2812B-B

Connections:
+3V3: C4.1, C5.1, C6.1, IC1.5 (OUT); also elsewhere on the board
+5V: C3.1, IC1.1 (IN), IC1.3 (EN), J1.A4 (VBUS_A), J1.A9 (VBUS_A), J1.B4 (VBUS_B), J1.B9 (VBUS_B), J2.1 (VCC), R8.2; also elsewhere on the board
GND: C3.2, C4.2, C5.2, C6.2, C7.1, IC1.2 (GND), J1.A1 (GND_A), J1.A12 (GND_A), J1.B1 (GND_B), J1.B12 (GND_B), J1.S3 (SHIELD), J1.S4 (SHIELD), J1.S5 (SHIELD), J1.S6 (SHIELD), J2.4 (GND), J2.S1 (SHIELD), J2.S2 (SHIELD), R9.1, U2.3 (VSS); also elsewhere on the board
unnamed: C7.2, R8.1, U2.1 (VDD)
unnamed: J1.A5 (CC), R9.2
RGB: U2.4 (DIN); also elsewhere on the board
USB_D+: J1.A6 (D+), J2.3 (D+); also elsewhere on the board
USB_D-: J1.A7 (D-), J2.2 (D-); also elsewhere on the board

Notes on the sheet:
USB INTERFACES

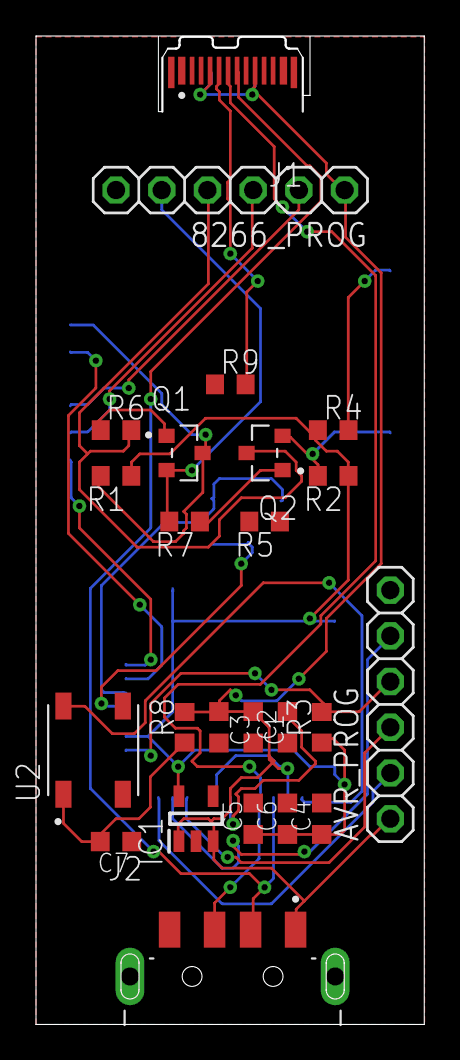
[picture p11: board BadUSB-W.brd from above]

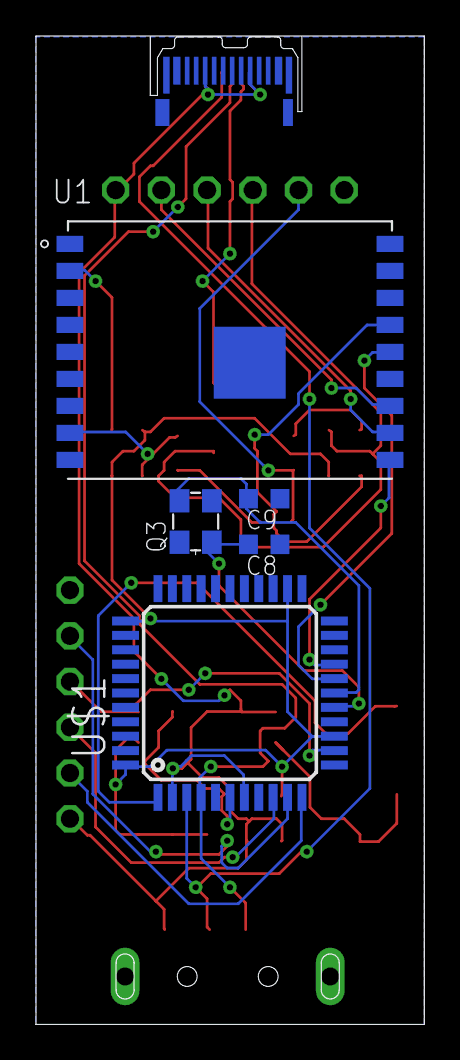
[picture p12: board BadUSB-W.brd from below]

Board: 2 copper layers, 21.6 x 54.9 mm, 29 parts (5 on the bottom side), 26 nets.

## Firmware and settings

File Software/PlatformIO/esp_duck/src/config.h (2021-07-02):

/*
   This software is licensed under the MIT License. See the license file for details.
   Source: https://github.com/spacehuhntech/WiFiDuck
 */

#pragma once

#define VERSION "1.0.4"

/*! ===== DEBUG Settings ===== */
#define ENABLE_DEBUG
#define DEBUG_PORT Serial
#define DEBUG_BAUD 115200

/*! ===== Communication Settings ===== */
// #define ENABLE_SERIAL
#define SERIAL_PORT Serial
#define SERIAL_BAUD 9600

#define ENABLE_I2C
#define I2C_ADDR 0x31
#define I2C_SDA 21
#define I2C_SCL 22
#define I2C_CLOCK_SPEED 100000L

#define BUFFER_SIZE 384
#define PACKET_SIZE 32

#define MSG_CONNECTED "LED 0 0 25\n"
#define MSG_STARTED "LED 0 25 0\n"

/*! ======EEPROM Settings ===== */
#define EEPROM_SIZE       4095
#define EEPROM_BOOT_ADDR  3210
#define BOOT_MAGIC_NUM    1234567890

/*! ===== WiFi Settings ===== */
#define WIFI_SSID "BadUSBw"
#define WIFI_PASSWORD "BadUSBW"
#define WIFI_CHANNEL "1"

#define HOSTNAME "badusb"
#define URL "bad.usb"

/*! ========== Safty checks ========== */
#if !defined(ENABLE_I2C) && !defined(ENABLE_SERIAL)
  #define ENABLE_I2C
  #define I2C_SDA 4
  #define I2C_SCL 5
#endif /* if !defined(ENABLE_I2C) || !defined(ENABLE_SERIAL) */

#if !defined(ESP32)
#error You are compiling for the wrong board, mate! Select something with an ESP32.
#endif /* ifdef DUCKMCU && DUCKMCU!="ATMEGA32U4" */

#if defined(ENABLE_DEBUG) && defined(ENABLE_SERIAL) && DEBUG_PORT == SERIAL_PORT
#error Using same serial port for debugging and Communication!\
    Use I2C instead or disable debug.
#endif /* if DEBUG_PORT == SERIAL_PORT */

#if defined(ENABLE_I2C) && I2C_SDA==I2C_SCL
#error SDA pin equals to SCL pin
#endif /* if !defined(ENABLE_I2C) && !defined(ENABLE_I2C) */

#if defined(ENABLE_I2C) && defined(ENABLE_SERIAL) && (I2C_SDA==1 || I2C_SDA==3 || I2C_SCL==1 || I2C_SCL==3)
#error I2C pins overlap with RX and TX pins. Disable serial debugging or change the I2C pins.
#endif /* if !defined(ENABLE_I2C) && !defined(ENABLE_I2C) */

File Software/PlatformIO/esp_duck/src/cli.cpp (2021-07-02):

/*!
   \file esp_duck/cli.cpp
   \brief Command line interface source
   \author Stefan Kremser
   \copyright MIT License
 */

#include "cli.h"
#include <SimpleCLI.h>

//=====================================
// Get Ram Usage Commented Out 30/06/21
//=====================================

// Get RAM (heap) usage
//extern "C" {
//#include "user_interface.h"
//}

// Import modules used for different commands
#include "spiffs.h"
#include "duckscript.h"
#include "settings.h"
#include "com.h"
#include "config.h"

namespace cli {
    // ===== PRIVATE ===== //
    SimpleCLI cli;           // !< Instance of SimpleCLI library

    PrintFunction printfunc; // !< Function used to print output

    /*!
     * \brief Internal print function
     *
     * Outputs a c-string using the currently set printfunc.
     * Helps to keep code readable.
     * It's only defined in the scope of this file!
     *
     * \param s String to printed
     */
    inline void print(const String& s) {
        if (printfunc) printfunc(s.c_str());
    }

    // ===== PUBLIC ===== //
    void begin() {
        /**
         * \brief Set error callback.
         *
         * Prints 'ERROR: <error-message>'
         * And 'Did you mean "<command-help>"?'
         * if the command name matched, but the arguments didn't
         */
        cli.setOnError([](cmd_error* e) {
            CommandError cmdError(e); // Create wrapper object

            String res = "ERROR: " + cmdError.toString();

            if (cmdError.hasCommand()) {
                res += "\nDid you mean \"";
                res += cmdError.getCommand().toString();
                res += "\"?";
            }

            print(res);
        });

        /**
         * \brief Create help Command
         *
         * Prints all available commands with their arguments
         */
        cli.addCommand("help", [](cmd* c) {
            print(cli.toString());
        });

        /**
         * \brief Create ram command
         *
         * Prints number of free bytes in the RAM
         */
        cli.addCommand("ram", [](cmd* c) {
            size_t freeRam = system_get_free_heap_size();
            String res     = String(freeRam) + " bytes available";
            print(res);
        });

        /**
         * \brief Create version command
         *
         * Prints the current version number
         */
        cli.addCommand("version", [](cmd* c) {
            String res = "Version " + String(VERSION) + " (" + String(com::getVersion()) + ")";
            print(res);
        });

        /**
         * \brief Create settings command
         *
         * Prints all settings with their values
         */
        cli.addCommand("settings", [](cmd* c) {
            settings::load();
            print(settings::toString());
        });

        /**
         * \brief Create set command
         *
         * Updates the value of a setting
         *
         * \param name name of the setting
         * \param vale new value for the setting
         */
        Command cmdSet {
            cli.addCommand("set", [](cmd* c) {
                Command  cmd { c };

                Argument argName { cmd.getArg(0) };
                Argument argValue { cmd.getArg(1) };

                String name { argName.getValue() };
                String value { argValue.getValue() };

                settings::set(name.c_str(), value.c_str());

                String response = "> set \"" + name + "\" to \"" + value + "\"";

                print(response);
            })
        };
        cmdSet.addPosArg("n/ame");
        cmdSet.addPosArg("v/alue");

        /**
         * \brief Create reset command
         *
         * Resets all settings and prints out the defaul values
         */
        cli.addCommand("reset", [](cmd* c) {
            settings::reset();
            print(settings::toString());
        });

        /**
         * \brief Create status command
         *
         * Prints status of i2c connection to atmega32u4:
         * running <script>
         * connected
         * i2c connection problem
         */
        cli.addCommand("status", [](cmd* c) {
            if (com::connected()) {
                if (duckscript::isRunning()) {
                    String s = "running " + duckscript::currentScript();
                    print(s);
                } else {
                    print("connected");
                }
            } else {
                print("Internal connection problem");
            }
        });

        /**
         * \brief Create ls command
         *
         * Prints a list of files inside of a given directory
         *
         * \param * Path to directory
         */
        cli.addSingleArgCmd("ls", [](cmd* c) {
            Command  cmd { c };
            Argument arg { cmd.getArg(0) };

            String res = spiffs::listDir(arg.getValue());
            print(res);
        });

        /**
         * \brief Create mem command
         *
         * Prints memory usage of SPIFFS
         */
        cli.addCommand("mem", [](cmd* c) {
            String s = "";
            s.reserve(64);

            s += String(spiffs::size());
            s += " byte\n";
            s += String(spiffs::usedBytes());
            s += " byte used\n";
            s += String(spiffs::freeBytes());
            s += " byte free";

            print(s);
        });

        /**
         * \brief Create cat command
         *
         * Prints out a file from the SPIFFS
         *
         * \param * Path to file
         */
        cli.addSingleArgCmd("cat", [](cmd* c) {
            Command  cmd { c };
            Argument arg { cmd.getArg(0) };

            File f = spiffs::open(arg.getValue());

            int buf_size { 256 };
            char buffer[buf_size];

            while (f && f.available()) {
                for (size_t i = 0; i<buf_size; ++i) {
                    if (!f.available() || (i == buf_size-1)) {
                        buffer[i] = '\0';
                        i         = buf_size;
                    } else {
                        buffer[i] = f.read();
                    }
                }
                print(buffer);
            }
        });

        /**
         * \brief Create run command
         *
         * Starts executing a ducky script
         *
         * \param * Path to script in SPIFFS
         */
        cli.addSingleArgCmd("run", [](cmd* c) {
            Command  cmd { c };
            Argument arg { cmd.getArg(0) };

            duckscript::run(arg.getValue());

            String response = "> started \"" + arg.getValue() + "\"";
            print(response);
        });
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

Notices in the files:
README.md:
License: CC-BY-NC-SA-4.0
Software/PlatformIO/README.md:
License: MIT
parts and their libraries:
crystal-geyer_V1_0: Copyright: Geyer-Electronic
